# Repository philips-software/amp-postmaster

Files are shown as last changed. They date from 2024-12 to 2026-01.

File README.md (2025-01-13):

# Postmaster (Programmer Of ST Microcontrollers Attached to ST Experiment boaRds)

<!-- markdownlint-disable -->

<!-- markdownlint enable -->

## Overview

Postmaster is a device that clicks on top of an STM32 Nucleo-F767ZI board from ST Microelectronics, and through its Ethernet connector you can program the Nucleo and communicate with it.

In this way, Postmaster is usable in hardware-in-the-loop tests, where a test board is reachable through the internet. That test board can first be programmed with the correct firmware. For communicating with the test board, a client can connect to Postmaster via a websocket connection, and talk to the attached board either via a plain UART connection, or via an [ECHO](https://philips-software.github.io/amp-embedded-infra-lib/embedded_infrastructure_library/7.0.0/Echo.html) connection. This communication line is used to execute tests.

Test boards enabled by Postmaster are intended to be inherently scalable; Adding tests boards in a setup should be as simple as putting a Postmaster on top of it, configuring the Postmaster with a few labels describing the characteristics of that board, and connecting it to the internet. A locally installed proxy (also part of this archive) provides discoverability of all Postmasters in its vicinity, and routes incoming requests for boards with certain characteristics to any available board.

By providing a schematics and PCB layout, the Postmaster firmware, and various tools, this repository aims to provide a full suite of components tackling all aspects of connecting a hardware-in-the-loop test board to the cloud.

Requirements of Postmaster are documented [here](Documents/Requirements.md).

## Community

This project uses the [CODE_OF_CONDUCT](./CODE_OF_CONDUCT.md) to define expected conduct in our community. Instances of abusive, harassing, or otherwise unacceptable behavior may be reported by contacting a project [CODEOWNER](.github/CODEOWNERS)

## Changelog

See [CHANGELOG](./CHANGELOG.md) for more info on what's been changed.

## Build

The Postmaster binaries can be built by executing the following commands:

```shell
cmake --preset stm32f407
cmake --build --preset stm32f407-MinSizeRel
```

The postmaster.flex utility can be build by executing the following commands:

```shell
cmake --preset host
cmake --build --preset host-RelWithDebInfo
```

## Reporting vulnerabilities

If you find a vulnerability, please report it to us!
See [security](.github/SECURITY.md) for more information.

## Licenses

See [LICENSE](./LICENSE.md)

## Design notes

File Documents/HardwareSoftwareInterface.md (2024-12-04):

# Postmaster Hardware Software Interface

## Document Introduction
This document describes the interface between the hardware and the software of the Postmaster. It describes which peripherals and pins are connected to the hardware on the board.

## Microcontroller

The Postmaster software runs on an STM32F407VE.

## Interface

### STM32 Nucleo-F767ZI

The Postmaster is connected to the STM32 Nucleo-F767ZI in this way:

| Postmaster | STM32 Nucleo-F767ZI |
|---|---|
| PB5 | Boot0 |
| PA10, UART1 RX | PC10 UART3/4 TX |
| PB6, UART1 TX  | PC11 UART3/4 RX |
| PB7, UART1 RX  | Extern Header TX |
| PA9, UART1 TX  | Extern Header RX |
| PB4 | nReset |
| PC7, UART6 RX  | PD8 UART3 TX |

### Display

The Display is a 128x32 pixels OLED displayed controlled by an SSD1306 chip. The address of this chip is 0x3c. This chip is connected over I2C (max. frequency 400kHz) in this way:

| Postmaster | SSD1306 |
|---|---|
| PB8, I2C1 SCL | SCL |
| PB9, I2C1 SDA | SDA |

### Flash

The Flash chip is a generic JEDEC serial NOR flash chip with at capacity of at least 2MB connected over SPI in this way:

| Postmaster | Flash |
|---|---|
| PA15 | CS |
| PC10, SPI3 CLK  | CLK |
| PC11, SPI3 MISO | MISO  |
| PC12, SPI3 MOSI | MOSI  |

### Ethernet

The Postmaster is connected to a LAN8710A Ethernet PHY chip via the SMI and RMII interfaces. Its SMI address is 0.

| Postmaster | Ethernet |
|---|---|
| PA2 | mdio |
| PC1 | mdc |
| PA1 | rmiiRefClk |
| PA7 | rmiiCrsDv  |
| PC4 | rmiiRxD0 |
| PC5 | rmiiRxD1 |
| PB11 | rmiiTxEn |
| PB12 | rmiiTxD0 |
| PB13 | rmiiTxD1 |

### Debug UART

The Debug UART is connected to the TDI and DBGRQ pins of the 20-pin J-Link Connector, which is presented over USB by the J-Link adapter as a virtual COM port.

| Postmaster | Debug UART |
|---|---|
| PD8, UART3 TX | J-Link-RX (DBGRQ, pin 17) |
| PD9, UART3 RX | J-Link-TX (TDI, pin 5) |

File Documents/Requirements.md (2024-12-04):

# Postmaster Requirements Specification

## Document Introduction
This document describes the product requirements and the functional behaviour of the Postmaster.

## Purpose
The Postmaster is a tool intended to be used to download firmware to an attached STM32 Nucleo-F767ZI Board, and to connect to that board over a UART connection. The firmware to download is provided to Postmaster via its network connection.

## Requirements
- The Postmaster attaches on top of an STM32 Nucleo-F767ZI board from ST Microelectronics via the Zio connector and the BOOT0 pin on the Morpho connector.
- The Postmaster draws its power from the Nucleo board to which it is attached.
- The Postmaster uses either the SWD or one of the boot loader protocols supported by the STM32F767 to upgrade the attached Nucleo-F767ZI
- The Postmaster connects to a TCP/IP network via an Ethernet connection.
- The Postmaster displays its current network status.
- The firmware of the Postmaster is remotely upgradeable.
- The Postmaster is programmable via a J-Link programmer.
- The Postmaster is discoverable via mDNS.
  - The DNS hostname is <name>.postmaster._tcp.local.
  - Advertised attributes in the TXT record are:
    - "nm", containing the Postmaster's configured name.
    - "vs", containing the version, in format <major>.<minor>.<patch>.
    - "vf", containing the full version, in format <version>.<commit hash>.
    - "at", containing the attributes describing the setup to which the Postmaster is attached to.
- The hostname is configurable; by default it contains information unique to the microcontroller of the Postmaster.
- Firmware for either the attached Nucleo-F767ZI or the Postmaster itself can be uploaded via the HTTP protocol.
  - The path to upgrade the Postmaster is /firmware/self.
  - The path to upgrade the attached Nucleo is /firmware/target.
- Several HTTP pages which accept POST requests are available, to distinguish between upgrading the Postmaster, upgrading the Nucleo-F767ZI, or patching (writing without erasing) the Nucleo-F767ZI.
- A user-friendly HTTP page is available for dragging/dropping firmware to be uploaded and for configuration.
- On booting, the Postmaster performs a self-test.
- An HTTP page is available that shows nearby detected Postmasters.
- The UART port with which the Postmaster communications with the attached Nucleo board can be configured to be either the same UART through which the Nucleo board is upgraded, or a secondary UART port.
- The HTTP connection can be upgraded to a WebSocket connection via which the Postmaster can talk to the attached Nucleo board over a UART port without interpretation of a protocol.
  - The path for the attached Nucleo is /target/uart/programmer.
  - The path for the external header is /target/uart/external.
- The HTTP connection can be upgraded to a WebSocket connection via which the Postmaster can talk to the attached Nucleo board over a UART port via the ECHO protocol.
  - The path for the attached Nucleo is /target/echo/programmer.
  - The path for the external header is /target/echo/external.

## Assumptions
- The Postmaster is used in a secure network. The Postmaster therefore does not need access control or other security measurements.

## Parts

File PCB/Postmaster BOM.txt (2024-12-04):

Partlist exported from C:/Dev/Postmaster/PCB/Postmaster/Postmaster.sch at 17/04/2022 20:07:00

Part Value                          Device                 Package                Description                
B1   BEADSMD                        BEADSMD                0805                                              
C1   100n                           CAPACITOR0805          0805                                              
C2   100n                           CAPACITOR0805          0805                                              
C3   100n                           CAPACITOR0805          0805                                              
C4   100n                           CAPACITOR0805          0805                                              
C5   100n                           CAPACITOR0805          0805                                              
C6   100n                           CAPACITOR0805          0805                                              
C7   100n                           CAPACITOR0805          0805                                              
C8   100n                           CAPACITOR0805          0805                                              
C9   10p                            CAPACITOR0805          0805                                              
C10  10p                            CAPACITOR0805          0805                                              
C11  10p                            CAPACITOR0805          0805                                              
C12  10p                            CAPACITOR0805          0805                                              
C13  22n                            CAPACITOR0805          0805                                              
C14  470p                           CAPACITOR0805          0805                                              
C15  1u                             CAPACITOR0805          0805                                              
C16  100n                           CAPACITOR0805          0805                                              
C17  100n                           CAPACITOR0805          0805                                              
C18  100n                           CAPACITOR0805          0805                                              
C19  100n                           CAPACITOR0805          0805                                              
C20  100n                           CAPACITOR0805          0805                                              
C21  10u                            CAPACITOR0805          0805                                              
C22  10u                            CAPACITOR0805          0805                                              
C23  10u                            CAPACITOR0805          0805                                              
C24  10u                            CAPACITOR0805          0805                                              
C25  10u                            CAPACITOR0805          0805                                              
C26  2u2                            CAPACITOR0805          0805                                              
C27  2u2                            CAPACITOR0805          0805                                              
IC1  STM32F407                      STM32F407              TQFP100                                           
IC2  S25FL116K                      S25FL116KW             SOIC8-WIDE                                        
IC3  DISPLAY_32_128_SSD1306         DISPLAY_32_128_SSD1306 DISPLAY_128_32_SSD1306                            
IC4  LAN8710A                       LAN8710A               QFN32                                             
IC5  X1G0044810012 SG7050CAN 50 MHZ SM77H                  SM77H                  3.3V CMOS Clock Oscillator 
Q1   8MHz                           RESONATOR-S            RESONATOR-SMALL                                   
R1   30                             RESISTORR0805          0805                                              
R2   2k2                            RESISTORR0805          0805                                              
R3   49.9                           RESISTORR0805          0805                                              
R4   49.9                           RESISTORR0805          0805                                              
R5   49.9                           RESISTORR0805          0805                                              
R6   49.9                           RESISTORR0805          0805                                              
R7   330                            RESISTORR0805          0805                                              
R8   330                            RESISTORR0805          0805                                              
R9   10k                            RESISTORR0805          0805                                              
R10  10k                            RESISTORR0805          0805                                              
R11  12k1                           RESISTORR0805          0805                                              
R12  10k                            RESISTORR0805          0805                                              
R13  2k2                            RESISTORR0805          0805                                              
R14  1k5                            RESISTORR0805          0805                                              
R16  10k                            RESISTORR0805          0805                                              
R17  10k                            RESISTORR0805          0805                                              
R18  10k                            RESISTORR0805          0805                                              
R19  10k                            RESISTORR0805          0805                                              
R20  10k                            RESISTORR0805          0805                                              
S1   SWITCHSMD                      SWITCHSMD              SWITCH-SMD                                        
SJ1                                 SJ                     SJ                     SMD solder JUMPER          
U$1  NUCLEO-TOPLEFT                 NUCLEO-TOPLEFT         NUCLEO-TOPLEFT                                    
X1   HEADER-IDC-10-2                HEADER-IDC-10-2        IDC-10_2                                          
X2   J00-0065NL                     J00-0065NL             ETHERNET

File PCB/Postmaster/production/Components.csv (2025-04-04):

Comment | Designator | Footprint | JLCPCBPart
22nF | C1 | Capacitor_SMD:C_0603_1608Metric | C21122
10p | C2,C3,C4,C5 | Capacitor_SMD:C_0603_1608Metric | C1634
10u | C6,C8,C12,C19,C22 | Capacitor_SMD:C_0603_1608Metric | C19702
100n | C7,C10,C13,C14,C15,C18,C20,C21,C23,C24,C25,C26,C27 | Capacitor_SMD:C_0603_1608Metric | C14663
470p | C9 | Capacitor_SMD:C_0603_1608Metric | C1620
1u | C11 | Capacitor_SMD:C_0805_2012Metric | C15849
2u2 | C16,C17 | Capacitor_SMD:C_0603_1608Metric | C23630
FerriteBead | FB1 | Inductor_SMD:L_0603_1608Metric | C1002
Conn_01x02 | J1 | Connector_PinSocket_2.54mm:PinSocket_1x02_P2.54mm_Vertical | C7509512
Conn_02x08_Odd_Even | J2 | Connector_PinHeader_2.54mm:PinHeader_2x08_P2.54mm_Vertical | C5383108
Conn_01x04 | J3,J4 | Connector_PinHeader_2.54mm:PinHeader_1x04_P2.54mm_Vertical | C7430360
Conn_01x03 | J5 | Connector_PinHeader_2.54mm:PinHeader_1x03_P2.54mm_Vertical
Conn_02x10_Odd_Even | J6 | Connector_IDC:IDC-Header_2x10_P2.54mm_Vertical | C3405
J00-0065NL | P1 | PostmasterParts:PULSE_J00-0065NL | C3178480
330 | R1,R2 | Resistor_SMD:R_0603_1608Metric | C23138
49.9 | R3,R4,R5,R6 | Resistor_SMD:R_0603_1608Metric | C269902
12k1 | R7 | Resistor_SMD:R_0603_1608Metric | C22864
10k | R8,R9,R10,R11,R12,R13,R14,R15 | Resistor_SMD:R_0603_1608Metric | C25804
1k5 | R16 | Resistor_SMD:R_0603_1608Metric | C22843
2k2 | R17,R18 | Resistor_SMD:R_0603_1608Metric | C4190
SW_Push | SW2 | Button_Switch_SMD:SW_SPST_TL3305B
LAN8710A | U1 | Package_DFN_QFN:QFN-32-1EP_5x5mm_P0.5mm_EP3.3x3.3mm_ThermalVias | C46185
STM32F407VETx | U2 | Package_QFP:LQFP-100_14x14mm_P0.5mm | C28730
S25FL064LABMFI013 | U3 | Package_SO:SOIC-8_5.23x5.23mm_P1.27mm | C2951282
TFOM50M4RHKCNT2T | Y1 | Oscillator:Oscillator_SMD_Abracon_ASE-4Pin_3.2x2.5mm | C454615
CSTNE8M00G550000R0 | Y2 | Crystal:Resonator_SMD_Murata_CSTxExxV-3Pin_3.0x1.1mm | C341522

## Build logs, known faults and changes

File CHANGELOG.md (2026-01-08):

# CHANGELOG

All notable changes to this project will be documented in this file.

The format is based on [Keep a Changelog](https://keepachangelog.com/) and this project adheres to [Semantic Versioning](https://semver.org/).

## unreleased

- Enabled warnings as error, requires CMake 3.24

## [0.5.0](https://github.com/philips-software/amp-postmaster/compare/v0.4.2...v0.5.0) (2026-01-08)

### Features

* **deps:** Bump the git-submodules group with 3 updates ([#157](https://github.com/philips-software/amp-postmaster/issues/157)) ([c72f827](https://github.com/philips-software/amp-postmaster/commit/c72f82746b9ce9e1db89811cab0ec1cbe0d8ef59))

### Bug Fixes

* Fill out content type and content length ([#165](https://github.com/philips-software/amp-postmaster/issues/165)) ([e9c7b0c](https://github.com/philips-software/amp-postmaster/commit/e9c7b0c233c8393ec904399f9182b687d82dedd9))
* Firmware upgrade ([#167](https://github.com/philips-software/amp-postmaster/issues/167)) ([95f315a](https://github.com/philips-software/amp-postmaster/commit/95f315a3d97898ae5ea2628a7af4c72bc2e6cbd3))
* Update display when hostname changes ([#168](https://github.com/philips-software/amp-postmaster/issues/168)) ([a214a2b](https://github.com/philips-software/amp-postmaster/commit/a214a2b18682dc2801df2f195e07964dcda485f7))

## [0.4.2](https://github.com/philips-software/amp-postmaster/compare/v0.4.1...v0.4.2) (2026-01-07)

### Bug Fixes

* Release version in upg file names ([#160](https://github.com/philips-software/amp-postmaster/issues/160)) ([20e5a0c](https://github.com/philips-software/amp-postmaster/commit/20e5a0c7634da09676dcf33ed5a433dc6a814ab6))

### Continuous Integration

* Substitute main version in upgrade pack ([e0ad9e0](https://github.com/philips-software/amp-postmaster/commit/e0ad9e03df9483b4bf938144bd519e11c37fa9e9))

## [0.4.1](https://github.com/philips-software/amp-postmaster/compare/v0.4.0...v0.4.1) (2026-01-05)

### Bug Fixes

* Create upgrade pack in release builds ([#155](https://github.com/philips-software/amp-postmaster/issues/155)) ([a97534e](https://github.com/philips-software/amp-postmaster/commit/a97534e0ec7223d1838d8aff6ec41813f2d24187))

## [0.4.0](https://github.com/philips-software/amp-postmaster/compare/v0.3.1...v0.4.0) (2026-01-05)

### Features

* **deps:** Bump the git-submodules group across 1 directory with 3 updates ([#153](https://github.com/philips-software/amp-postmaster/issues/153)) ([c136812](https://github.com/philips-software/amp-postmaster/commit/c1368121505cd80a841d12cf738da41e73dda4e1))

### Bug Fixes

* Install postmaster binaries ([#146](https://github.com/philips-software/amp-postmaster/issues/146)) ([8429844](https://github.com/philips-software/amp-postmaster/commit/842984459ac9b12047a313f3510fe26addfba380))

## [0.3.1](https://github.com/philips-software/amp-postmaster/compare/v0.3.0...v0.3.1) (2025-12-19)

### Bug Fixes

* Remove provenance and devcontainer templates ([#144](https://github.com/philips-software/amp-postmaster/issues/144)) ([d9b699c](https://github.com/philips-software/amp-postmaster/commit/d9b699c77f3d389f975c6d5e6fca4d7e41745df3))

## [0.3.0](https://github.com/philips-software/amp-postmaster/compare/v0.2.0...v0.3.0) (2025-12-19)

### Features

* **deps:** Bump the git-submodules group across 1 directory with 3 updates ([#141](https://github.com/philips-software/amp-postmaster/issues/141)) ([a58cd70](https://github.com/philips-software/amp-postmaster/commit/a58cd70d755250cc557a9f6fa9cc9cd275da8494))

## [0.2.0](https://github.com/philips-software/amp-postmaster/compare/v0.1.0...v0.2.0) (2025-12-17)

### Features

* Add kicad design for Postmaster ([#51](https://github.com/philips-software/amp-postmaster/issues/51)) ([5b0d990](https://github.com/philips-software/amp-postmaster/commit/5b0d9900bc231ba2a10e43529f035f32f8af2cdc))
* **deps:** Bump the git-submodules group across 1 directory with 3 updates ([#65](https://github.com/philips-software/amp-postmaster/issues/65)) ([9473c1d](https://github.com/philips-software/amp-postmaster/commit/9473c1d3efd021cd0ad530f573b0ce2613c047ab))
* Publish flex docker image ([#5](https://github.com/philips-software/amp-postmaster/issues/5)) ([e3fc05b](https://github.com/philips-software/amp-postmaster/commit/e3fc05ba389df427653b57ea76c12f334beb6b95))

### Bug Fixes

* Add tests for FlashAligner and fix it ([#88](https://github.com/philips-software/amp-postmaster/issues/88)) ([2133475](https://github.com/philips-software/amp-postmaster/commit/2133475931bbcfbf4f7fa093ad749119efa9695c))
* Align flash writes to 16 bytes ([#80](https://github.com/philips-software/amp-postmaster/issues/80)) ([0e34eeb](https://github.com/philips-software/amp-postmaster/commit/0e34eeb55f1ba87ccf2061490d2d1f1caafac746))
* Attach from correct SharedPtr ([f00cf1e](https://github.com/philips-software/amp-postmaster/commit/f00cf1e85892faf4e9c6b0aa95d7596bd946d101))
* Fix various problems ([42f0029](https://github.com/philips-software/amp-postmaster/commit/42f00295daf3bd058f0f94b6982cb21b694c2bf2))
* Incorrect tag in dockerfile causes devcontainer build failure ([#118](https://github.com/philips-software/amp-postmaster/issues/118)) ([31f71a4](https://github.com/philips-software/amp-postmaster/commit/31f71a4e9d64e9834987886dd61a1d6c54a75a64))
* Various Echo fixes ([220c4be](https://github.com/philips-software/amp-postmaster/commit/220c4be60fb67f997dff082bfabd027347f24174))

## v0.0.1

- Example Release

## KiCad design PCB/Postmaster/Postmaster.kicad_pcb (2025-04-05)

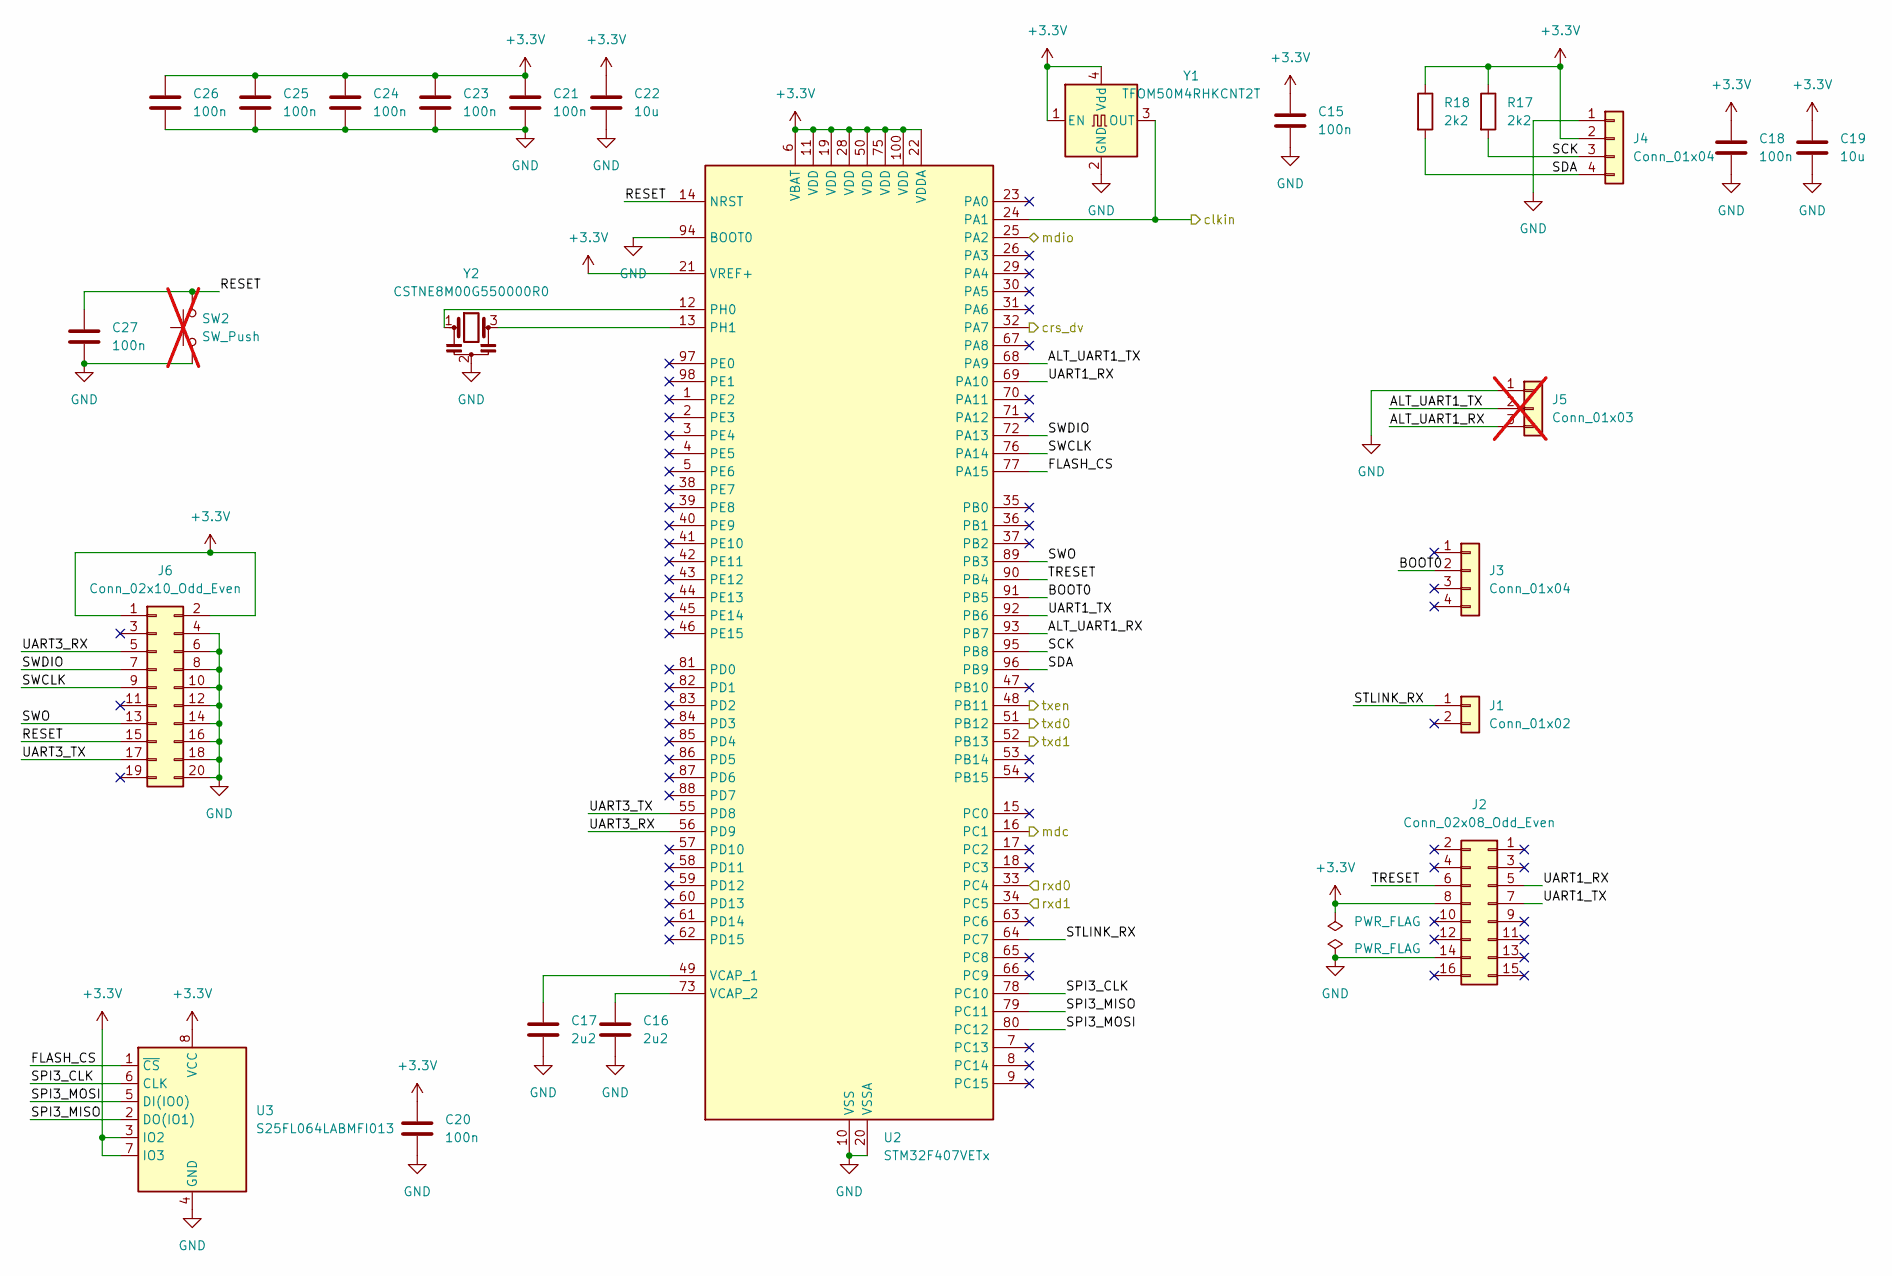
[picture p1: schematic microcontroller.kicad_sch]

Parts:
C15, C18, C20, C21, C23, C24, C25, C26, C27: 100n; C_0603_1608Metric; JLCPCBPart C14663
C16, C17: 2u2; C_0603_1608Metric; JLCPCBPart C23630
C19, C22: 10u; C_0603_1608Metric; JLCPCBPart C19702
J1: Conn_01x02; PinSocket_1x02_P2.54mm_Vertical; JLCPCBPart C7509512
J2: Conn_02x08_Odd_Even; PinHeader_2x08_P2.54mm_Vertical; JLCPCBPart C5383108
J3, J4: Conn_01x04; PinHeader_1x04_P2.54mm_Vertical; JLCPCBPart C7430360
J5: Conn_01x03; PinHeader_1x03_P2.54mm_Vertical; not fitted
J6: Conn_02x10_Odd_Even; IDC-Header_2x10_P2.54mm_Vertical; JLCPCBPart C3405
R17, R18: 2k2; R_0603_1608Metric; JLCPCBPart C4190
SW2: SW_Push; SW_SPST_TL3305B; not fitted
U2: STM32F407VETx; LQFP-100_14x14mm_P0.5mm; JLCPCBPart C28730
U3: S25FL064LABMFI013; SOIC-8_5.23x5.23mm_P1.27mm; JLCPCBPart C2951282
Y1: TFOM50M4RHKCNT2T; Oscillator_SMD_Abracon_ASE-4Pin_3.2x2.5mm; JLCPCBPart C454615
Y2: CSTNE8M00G550000R0; Resonator_SMD_Murata_CSTxExxV-3Pin_3.0x1.1mm; JLCPCBPart C341522

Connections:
+3.3V: C15.1, C18.1, C19.1, C20.1, C21.1, C22.1, C23.1, C24.1, C25.1, C26.1, J2.8, J4.2, J6.1, J6.2, R17.1, R18.1, U2.6 (VBAT), U2.11 (VDD), U2.19 (VDD), U2.21 (VREF+), U2.22 (VDDA), U2.28 (VDD), U2.50 (VDD), U2.75 (VDD), U2.100 (VDD), U3.3 (IO2), U3.7 (IO3), U3.8 (VCC), Y1.1 (EN), Y1.4 (Vdd); also elsewhere on the board
/Ethernet/clkin: U2.24 (PA1), Y1.3 (OUT); also elsewhere on the board
/Ethernet/crs_dv: U2.32 (PA7); also elsewhere on the board
/Ethernet/mdc: U2.16 (PC1); also elsewhere on the board
/Ethernet/mdio: U2.25 (PA2); also elsewhere on the board
/Ethernet/rxd0: U2.33 (PC4); also elsewhere on the board
/Ethernet/rxd1: U2.34 (PC5); also elsewhere on the board
/Ethernet/txd0: U2.51 (PB12); also elsewhere on the board
/Ethernet/txd1: U2.52 (PB13); also elsewhere on the board
/Ethernet/txen: U2.48 (PB11); also elsewhere on the board
/Microcontroller/ALT_UART1_RX: J5.3, U2.93 (PB7)
/Microcontroller/ALT_UART1_TX: J5.2, U2.68 (PA9)
/Microcontroller/BOOT0: J3.2, U2.91 (PB5)
/Microcontroller/FLASH_CS: U2.77 (PA15), U3.1 (~CS)
/Microcontroller/RESET: C27.1, J6.15, SW2.2, U2.14 (NRST)
/Microcontroller/SCK: J4.3, R17.2, U2.95 (PB8)
/Microcontroller/SDA: J4.4, R18.2, U2.96 (PB9)
/Microcontroller/SPI3_CLK: U2.78 (PC10), U3.6 (CLK)
/Microcontroller/SPI3_MISO: U2.79 (PC11), U3.2 (DO(IO1))
/Microcontroller/SPI3_MOSI: U2.80 (PC12), U3.5 (DI(IO0))
/Microcontroller/STLINK_RX: J1.1, U2.64 (PC7)
/Microcontroller/SWCLK: J6.9, U2.76 (PA14)
/Microcontroller/SWDIO: J6.7, U2.72 (PA13)
/Microcontroller/SWO: J6.13, U2.89 (PB3)
/Microcontroller/TRESET: J2.6, U2.90 (PB4)
/Microcontroller/UART1_RX: J2.5, U2.69 (PA10)
/Microcontroller/UART1_TX: J2.7, U2.92 (PB6)
/Microcontroller/UART3_RX: J6.5, U2.56 (PD9)
/Microcontroller/UART3_TX: J6.17, U2.55 (PD8)
GND: C15.2, C16.2, C17.2, C18.2, C19.2, C20.2, C21.2, C22.2, C23.2, C24.2, C25.2, C26.2, C27.2, J2.14, J4.1, J5.1, J6.4, J6.6, J6.8, J6.10, J6.12, J6.14, J6.16, J6.18, J6.20, SW2.1, U2.10 (VSS), U2.20 (VSSA), U2.27 (VSS), U2.74 (VSS), U2.94 (BOOT0), U2.99 (VSS), U3.4 (GND), Y1.2 (GND), Y2.2; also elsewhere on the board
unnamed: U2.12 (PH0), Y2.1
unnamed: U2.13 (PH1), Y2.3
unnamed: C17.1, U2.49 (VCAP_1)
unnamed: C16.1, U2.73 (VCAP_2)

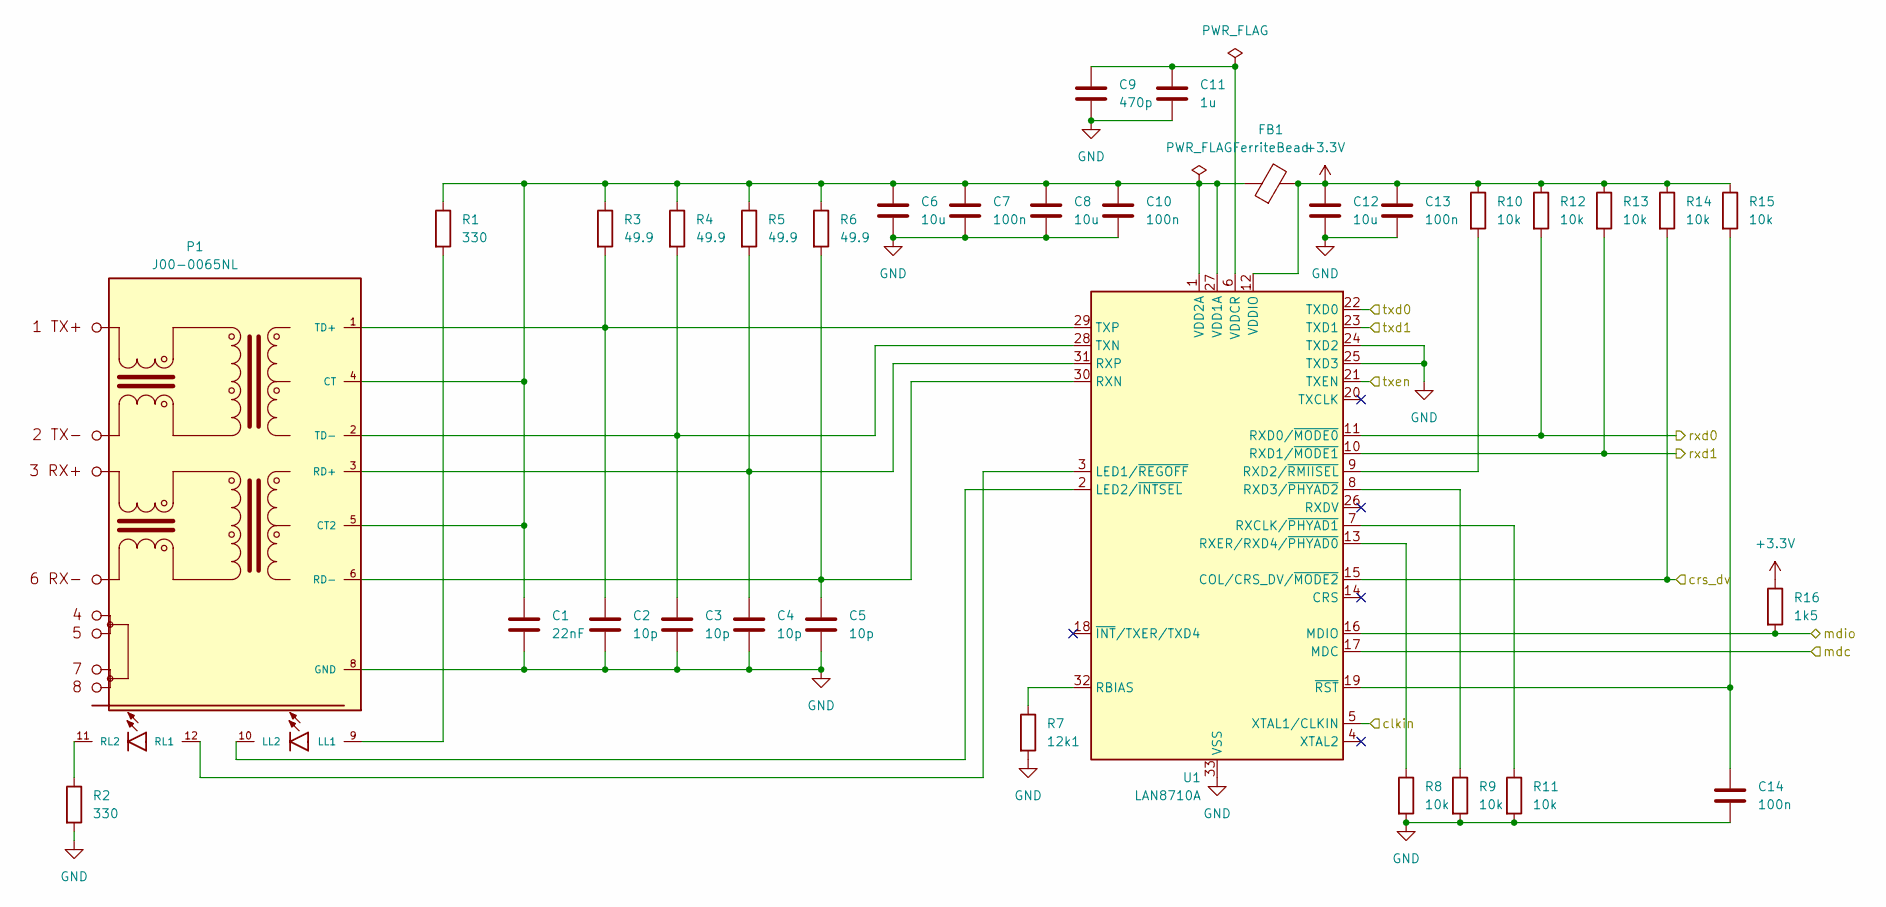
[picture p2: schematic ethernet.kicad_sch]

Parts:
C1: 22nF; C_0603_1608Metric; JLCPCBPart C21122
C2, C3, C4, C5: 10p; C_0603_1608Metric; JLCPCBPart C1634
C6, C8, C12: 10u; C_0603_1608Metric; JLCPCBPart C19702
C7, C10, C13, C14: 100n; C_0603_1608Metric; JLCPCBPart C14663
C9: 470p; C_0603_1608Metric; JLCPCBPart C1620
C11: 1u; C_0805_2012Metric; JLCPCBPart C15849
FB1: FerriteBead; L_0603_1608Metric; JLCPCBPart C1002
P1: J00-0065NL; PULSE_J00-0065NL; JLCPCBPart C3178480
R1, R2: 330; R_0603_1608Metric; JLCPCBPart C23138
R3, R4, R5, R6: 49.9; R_0603_1608Metric; JLCPCBPart C269902
R7: 12k1; R_0603_1608Metric; JLCPCBPart C22864
R8, R9, R10, R11, R12, R13, R14, R15: 10k; R_0603_1608Metric; JLCPCBPart C25804
R16: 1k5; R_0603_1608Metric; JLCPCBPart C22843
U1: LAN8710A; QFN-32-1EP_5x5mm_P0.5mm_EP3.3x3.3mm_ThermalVias; JLCPCBPart C46185

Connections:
+3.3V: C12.1, C13.1, FB1.2, R10.1, R12.1, R13.1, R14.1, R15.1, R16.1, U1.12 (VDDIO); also elsewhere on the board
/Ethernet/clkin: U1.5 (XTAL1/CLKIN); also elsewhere on the board
/Ethernet/crs_dv: R14.2, U1.15 (COL/CRS_DV/~MODE2); also elsewhere on the board
/Ethernet/mdc: U1.17 (MDC); also elsewhere on the board
/Ethernet/mdio: R16.2, U1.16 (MDIO); also elsewhere on the board
/Ethernet/rxd0: R12.2, U1.11 (RXD0/~MODE0); also elsewhere on the board
/Ethernet/rxd1: R13.2, U1.10 (RXD1/~MODE1); also elsewhere on the board
/Ethernet/txd0: U1.22 (TXD0); also elsewhere on the board
/Ethernet/txd1: U1.23 (TXD1); also elsewhere on the board
/Ethernet/txen: U1.21 (TXEN); also elsewhere on the board
GND: C1.2, C2.2, C3.2, C4.2, C5.2, C6.2, C7.2, C8.2, C9.2, C10.2, C11.2, C12.2, C13.2, C14.2, P1.8 (GND), R2.2, R7.2, R8.2, R9.2, R11.2, U1.24 (TXD2), U1.25 (TXD3), U1.33 (VSS); also elsewhere on the board
unnamed: C1.1, C6.1, C7.1, C8.1, C10.1, FB1.1, P1.4 (CT), P1.5 (CT2), R1.1, R3.1, R4.1, R5.1, R6.1, U1.1 (VDD2A), U1.27 (VDD1A)
unnamed: P1.9 (LL1), R1.2
unnamed: P1.10 (LL2), U1.2 (LED2/~INTSEL)
unnamed: C4.1, P1.3 (RD+), R5.2, U1.31 (RXP)
unnamed: C5.1, P1.6 (RD-), R6.2, U1.30 (RXN)
unnamed: P1.12 (RL1), U1.3 (LED1/~REGOFF)
unnamed: P1.11 (RL2), R2.1
unnamed: C2.1, P1.1 (TD+), R3.2, U1.29 (TXP)
unnamed: C3.1, P1.2 (TD-), R4.2, U1.28 (TXN)
unnamed: R7.1, U1.32 (RBIAS)
unnamed: R11.1, U1.7 (RXCLK/~PHYAD1)
unnamed: R10.2, U1.9 (RXD2/~RMIISEL)
unnamed: R9.1, U1.8 (RXD3/~PHYAD2)
unnamed: R8.1, U1.13 (RXER/RXD4/~PHYAD0)
unnamed: C9.1, C11.1, U1.6 (VDDCR)
unnamed: C14.1, R15.2, U1.19 (~RST)

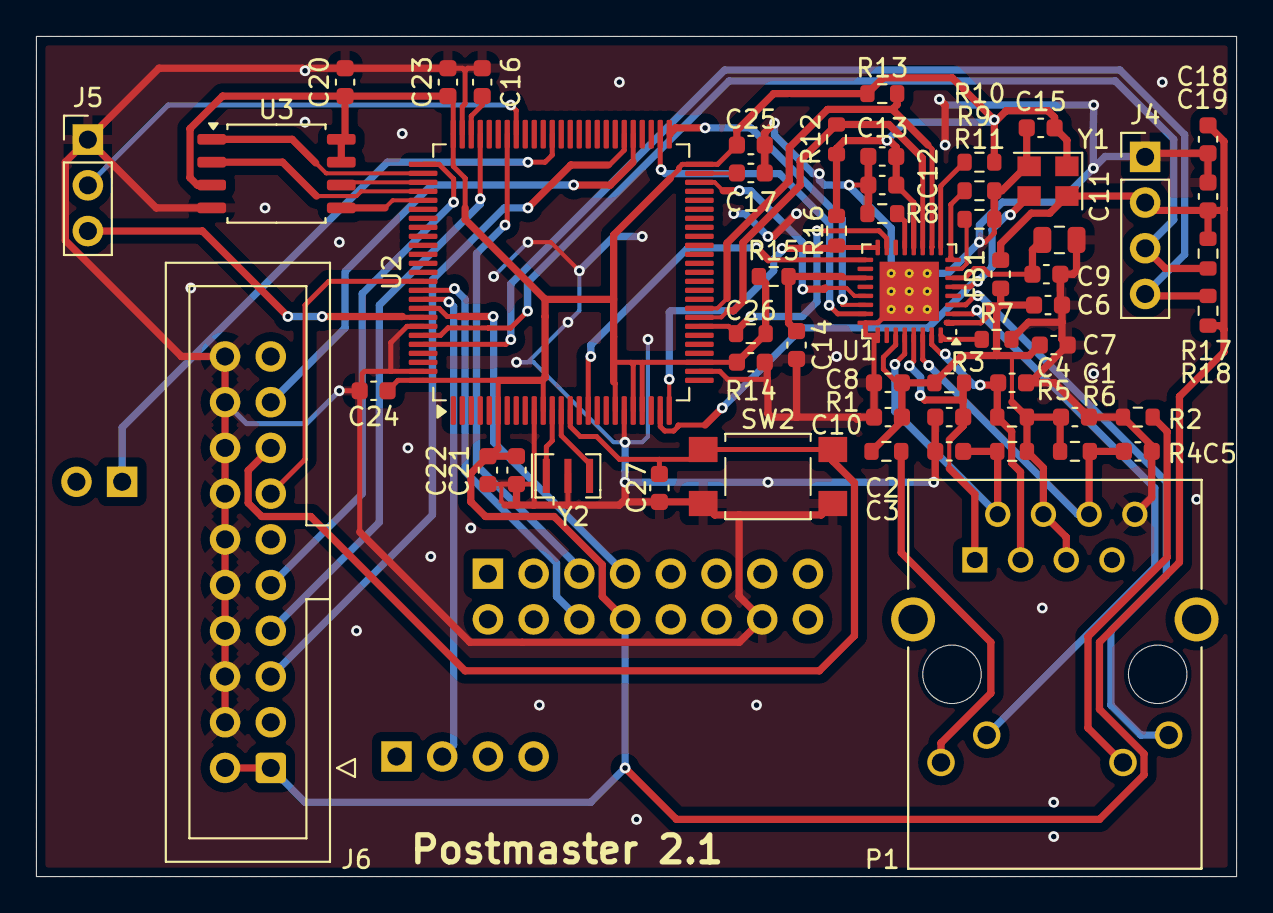
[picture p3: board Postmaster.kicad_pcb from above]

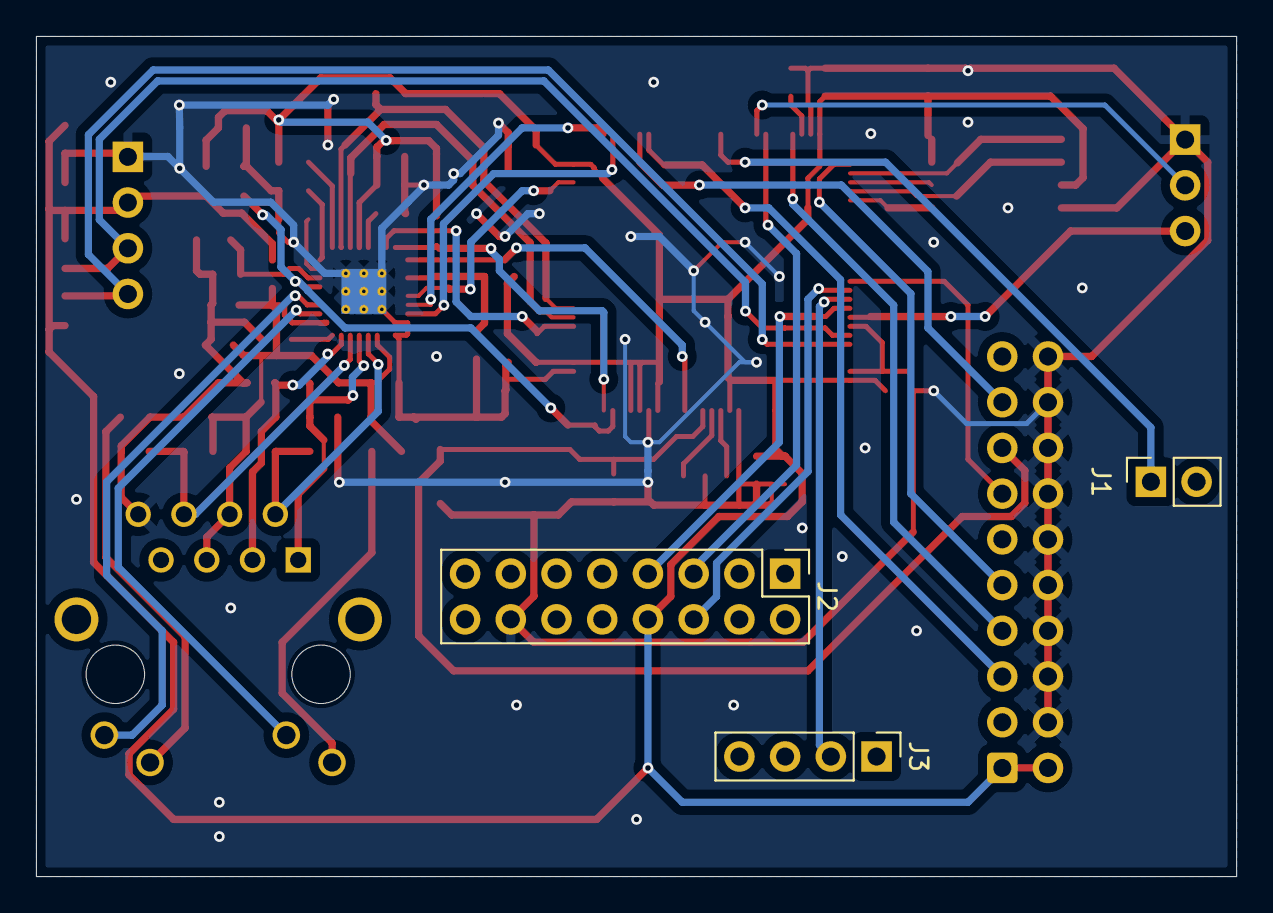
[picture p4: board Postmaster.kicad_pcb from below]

Board: 2 copper layers, 66.7 x 46.7 mm, 59 parts (3 on the bottom side), 50 nets.

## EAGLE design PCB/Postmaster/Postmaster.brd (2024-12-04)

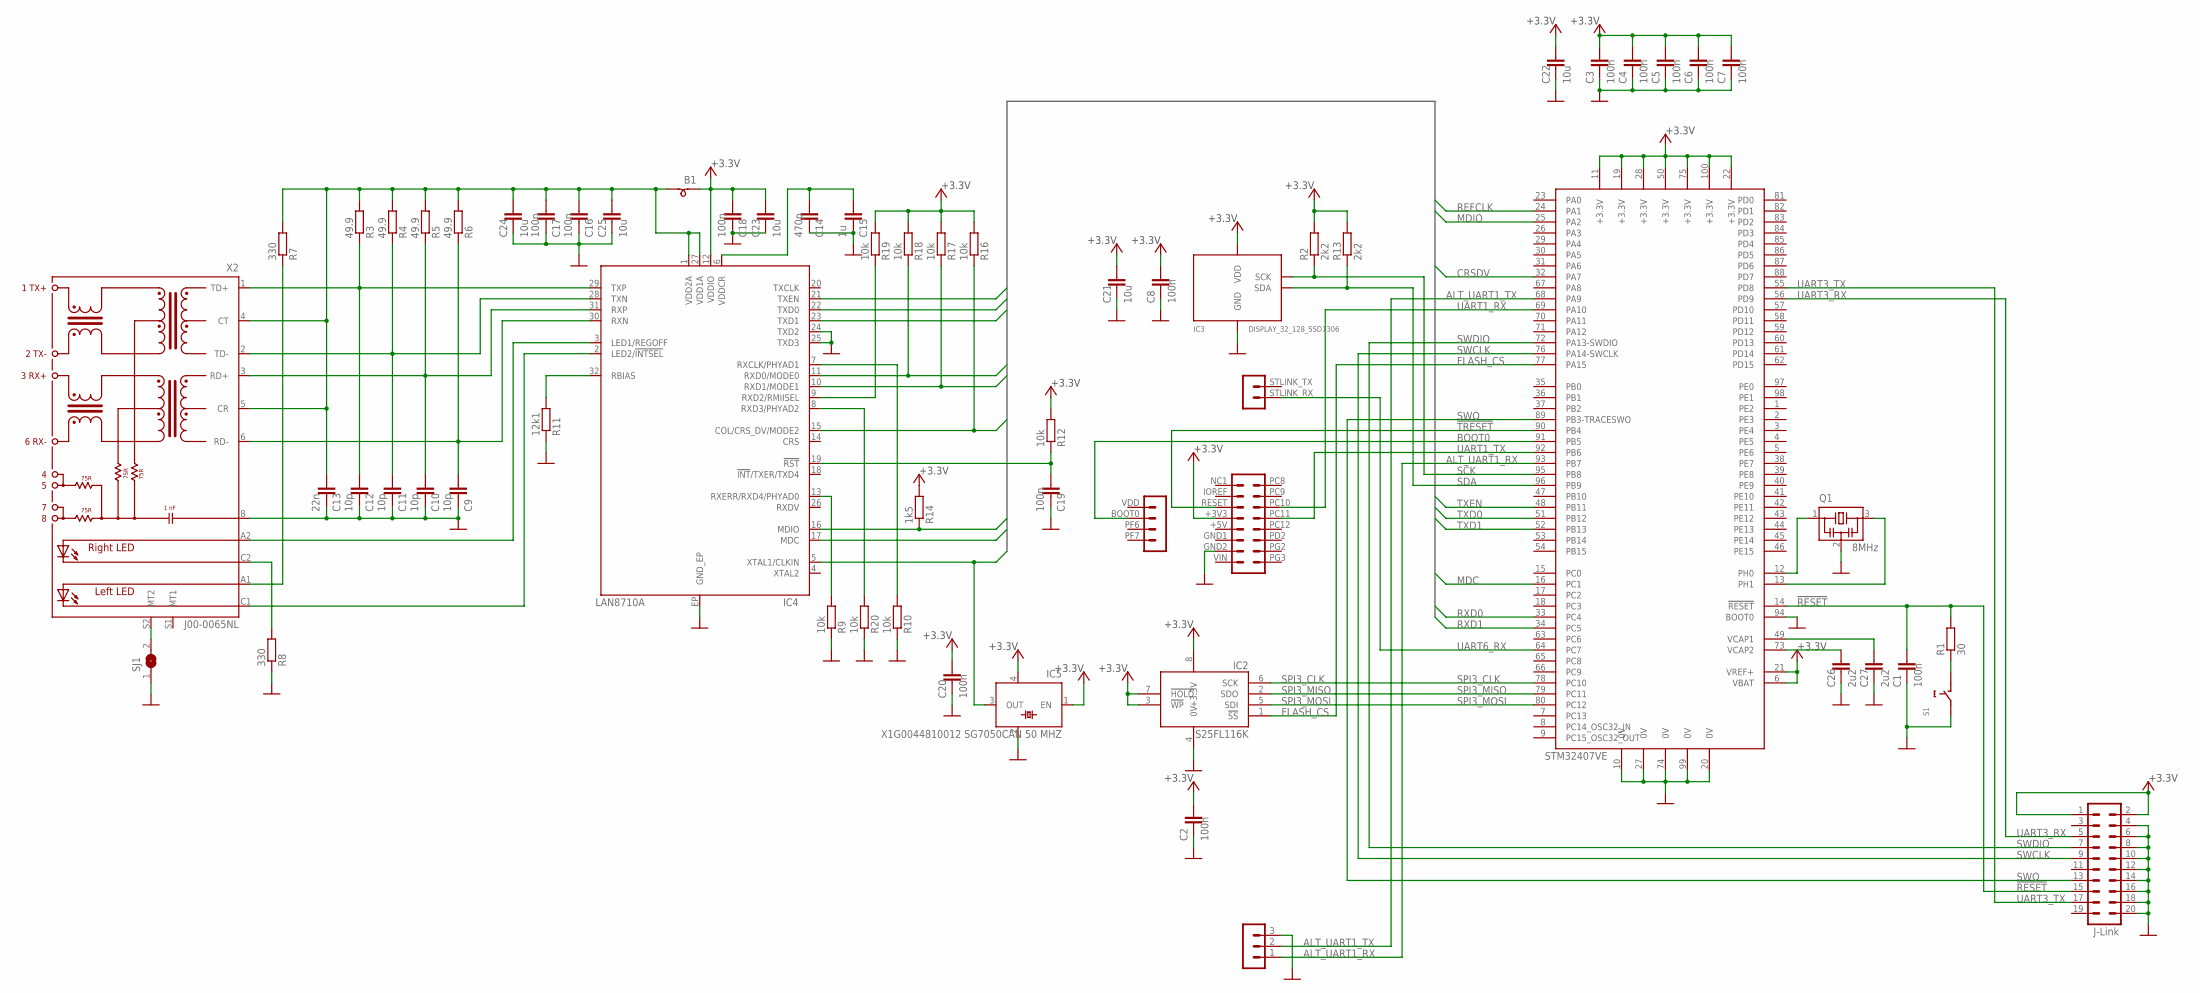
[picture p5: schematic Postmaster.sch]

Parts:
B1: BEADSMD; 0805
C1, C2, C3, C4, C5, C6, C7, C8, C16, C17, C18, C19, C20: 100n; 0805
C9, C10, C11, C12: 10p; 0805
C13: 22n; 0805
C14: 470p; 0805
C15: 1u; 0805
C21, C22, C23, C24, C25: 10u; 0805
C26, C27: 2u2; 0805
IC1: STM32F407; TQFP100
IC2: S25FL116K; SOIC8-WIDE
IC3: DISPLAY_32_128_SSD1306; DISPLAY_128_32_SSD1306
IC4: LAN8710A; QFN32
IC5: X1G0044810012 SG7050CAN 50 MHZ; SM77H
Q1: 8MHz; RESONATOR-SMALL
R1: 30; 0805
R2, R13: 2k2; 0805
R3, R4, R5, R6: 49.9; 0805
R7, R8: 330; 0805
R9, R10, R12, R16, R17, R18, R19, R20: 10k; 0805
R11: 12k1; 0805
R14: 1k5; 0805
S1: SWITCHSMD; SWITCH-SMD
SJ1: SJ
U$1: NUCLEO-TOPLEFT
U$3: HEADER-MALE-3
X1: HEADER-IDC-10-2; IDC-10_2
X2: J00-0065NL; ETHERNET

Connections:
0V: C1.2, C2.2, C3.2, C4.2, C5.2, C6.2, C7.2, C8.2, C9.2, C10.2, C11.2, C12.2, C13.2, C14.2, C15.2, C16.2, C17.2, C18.2, C19.2, C20.2, C21.2, C22.2, C23.2, C24.2, C25.2, C26.2, C27.2, IC1.10 (0V), IC1.20 (0V), IC1.27 (0V), IC1.74 (0V), IC1.94 (BOOT0), IC1.99 (0V), IC2.4 (0V), IC3.GND, IC4.24 (TXD2), IC4.25 (TXD3), IC4.EP (GND_EP), IC5.2 (0V), Q1.2, R8.1, R9.1, R10.1, R11.1, R20.1, S1.3 (2), S1.4 (2), SJ1.1, U$1.GND2 (13), U$3.3, X1.4, X1.6, X1.8, X1.10, X1.12, X1.14, X1.16, X1.18, X1.20, X2.8
!RESET!: C1.1, IC1.14 (!RESET!), R1.2, X1.15
!TRESET!: IC1.90 (PB4), U$1.RESET (5)
+3.3V: B1.1, C2.1, C3.1, C4.1, C5.1, C6.1, C7.1, C8.1, C18.1, C20.1, C21.1, C22.1, C23.1, IC1.6 (VBAT), IC1.11 (+3.3V), IC1.19 (+3.3V), IC1.21 (VREF+), IC1.22 (+3.3V), IC1.28 (+3.3V), IC1.50 (+3.3V), IC1.75 (+3.3V), IC1.100 (+3.3V), IC2.3 (!WP!), IC2.7 (!HOLD!), IC2.8 (+3.3V), IC3.VCC (VDD), IC4.12 (VDDIO), IC5.1 (EN), IC5.4 (+3.3V), R2.2, R12.2, R13.2, R14.2, R16.2, R17.2, R18.2, R19.2, U$1.+3V3 (7), X1.1, X1.2
ALT_UART1_RX: IC1.93 (PB7), U$3.1
ALT_UART1_TX: IC1.68 (PA9), U$3.2
BOOT0: IC1.91 (PB5), U$1.BOOT0 (2)
CRSDV: IC1.32 (PA7), IC4.15 (COL/CRS_DV/MODE2), R16.1
FLASH_CS: IC1.77 (PA15), IC2.1 (!SS!)
MDC: IC1.16 (PC1), IC4.17 (MDC)
MDIO: IC1.25 (PA2), IC4.16 (MDIO), R14.1
unnamed: C26.1, IC1.73 (VCAP2)
unnamed: R1.1, S1.1, S1.2 (1)
unnamed: C27.1, IC1.49 (VCAP1)
unnamed: R7.1, X2.A1 (A-L)
unnamed: IC4.3 (LED1/REGOFF), X2.A2 (A-R)
unnamed: R8.2, X2.C2 (C-R)
unnamed: IC1.12 (PH0), Q1.1
unnamed: IC1.13 (PH1), Q1.3
unnamed: C12.1, IC4.29 (TXP), R3.1, X2.1 (TD+)
unnamed: C11.1, IC4.28 (TXN), R4.1, X2.2 (TD-)
unnamed: C10.1, IC4.31 (RXP), R5.1, X2.3 (RD+)
unnamed: C9.1, IC4.30 (RXN), R6.1, X2.6 (RD-)
unnamed: IC4.2 (LED2/!INTSEL!), X2.C1 (C-L)
unnamed: IC4.13 (RXERR/RXD4/PHYAD0), R9.2
unnamed: IC4.7 (RXCLK/PHYAD1), R10.2
unnamed: IC4.32 (RBIAS), R11.2
unnamed: C14.1, C15.1, IC4.6 (VDDCR)
unnamed: SJ1.2, X2.S2 (MT2)
unnamed: B1.2, C13.1, C16.1, C17.1, C24.1, C25.1, IC4.1 (VDD2A), IC4.27 (VDD1A), R3.2, R4.2, R5.2, R6.2, R7.2, X2.4 (CT), X2.5 (CR)
unnamed: C19.1, IC4.19 (!RST!), R12.1
unnamed: IC4.8 (RXD3/PHYAD2), R20.2
unnamed: IC4.9 (RXD2/RMIISEL), R19.1
REFCLK: IC1.24 (PA1), IC4.5 (XTAL1/CLKIN), IC5.3 (OUT)
RXD0: IC1.33 (PC4), IC4.11 (RXD0/MODE0), R18.1
RXD1: IC1.34 (PC5), IC4.10 (RXD1/MODE1), R17.1
SCK: IC1.95 (PB8), IC3.SCK, R2.1
SDA: IC1.96 (PB9), IC3.SDA, R13.1
SPI3_CLK: IC1.78 (PC10), IC2.6 (SCK)
SPI3_MISO: IC1.79 (PC11), IC2.2 (SDO)
SPI3_MOSI: IC1.80 (PC12), IC2.5 (SDI)
SWCLK: IC1.76 (PA14-SWCLK), X1.9
SWDIO: IC1.72 (PA13-SWDIO), X1.7
SWO: IC1.89 (PB3-TRACESWO), X1.13
TXD0: IC1.51 (PB12), IC4.22 (TXD0)
TXD1: IC1.52 (PB13), IC4.23 (TXD1)
TXEN: IC1.48 (PB11), IC4.21 (TXEN)
UART1_RX: IC1.69 (PA10), U$1.PC10 (6)
UART1_TX: IC1.92 (PB6), U$1.PC11 (8)
UART3_RX: IC1.56 (PD9), X1.5
UART3_TX: IC1.55 (PD8), X1.17
UART6_RX: IC1.64 (PC7), U$1.STLINK_RX (1)

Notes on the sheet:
J-Link
STM32407VE

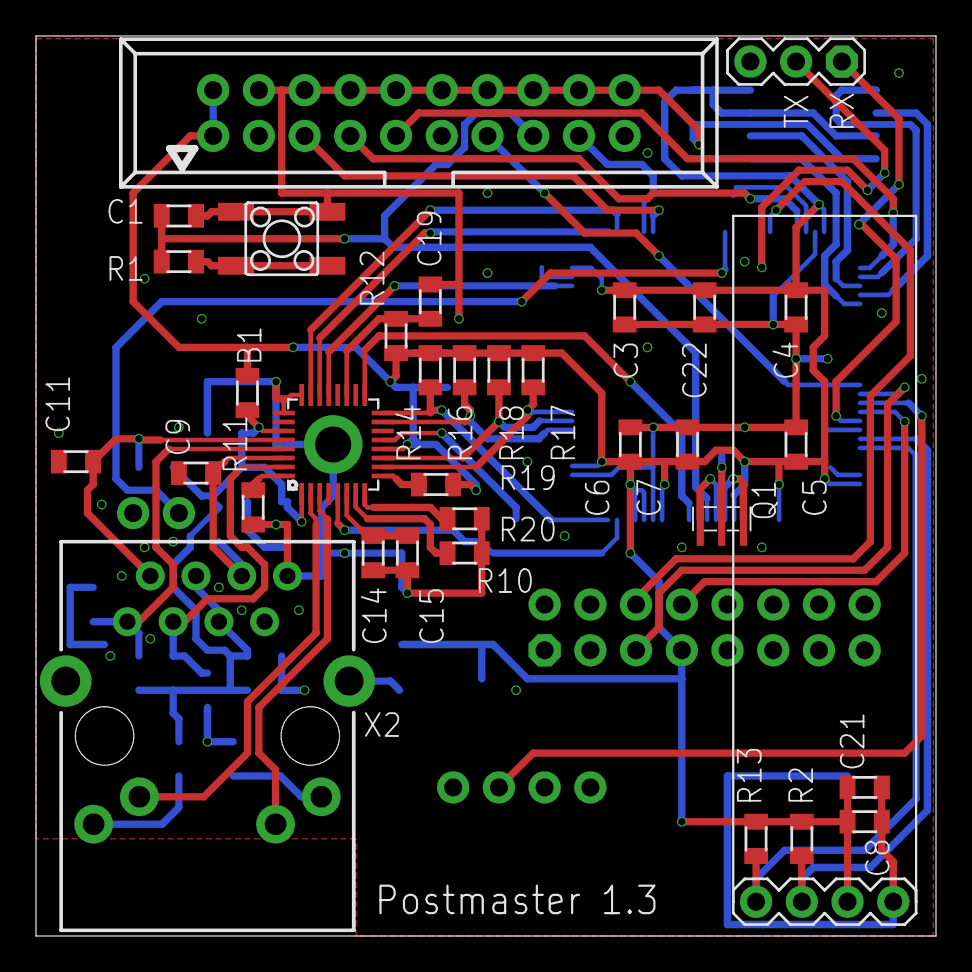
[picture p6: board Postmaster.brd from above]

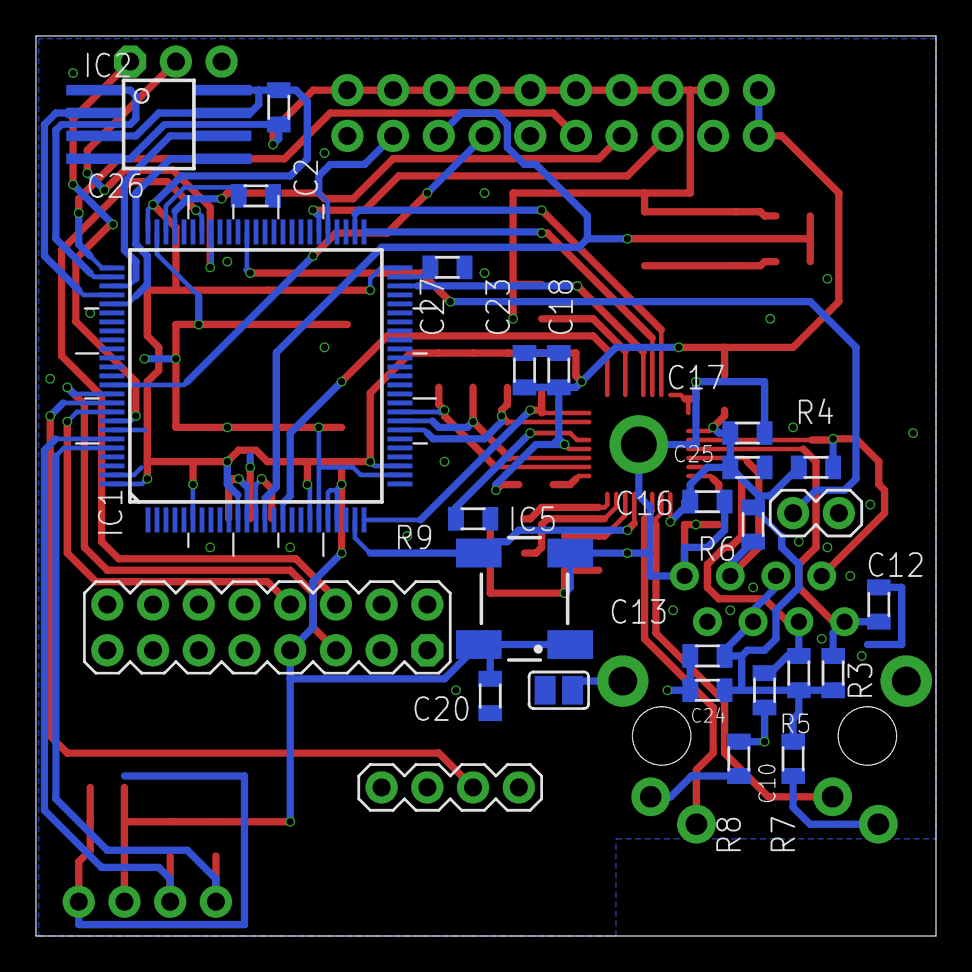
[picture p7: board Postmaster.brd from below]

Board: 2 copper layers, 50.0 x 50.0 mm, 59 parts (25 on the bottom side), 52 nets.

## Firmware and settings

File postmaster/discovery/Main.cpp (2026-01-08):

// Start Traefik with: docker run -it --rm -p 80:80 -p 8080:8080 traefik:v2.10 --api.insecure=true --providers.http.endpoint=http://host.docker.internal:9000/api --log.level=DEBUG

#include "hal/generic/TimerServiceGeneric.hpp"
#include "infra/stream/StdStringOutputStream.hpp"
#include "infra/syntax/JsonFormatter.hpp"
#include "postmaster/application/MdnsDiscovery.hpp"
#include "services/network/Http.hpp"
#include "services/network/HttpErrors.hpp"
#include "services/network/HttpServer.hpp"
#include "services/network_instantiations/NetworkAdapter.hpp"
#include "services/tracer/GlobalTracer.hpp"

class HttpPageReverseProxyConfiguration
    : public services::SimpleHttpPage
    , protected services::HttpResponse
{
public:
    HttpPageReverseProxyConfiguration(infra::BoundedConstString path, application::PostmasterDiscovery& discovery);

    // Implementation of SimpleHttpPage
    bool ServesRequest(const infra::Tokenizer& pathTokens) const override;
    void RespondToRequest(services::HttpRequestParser& parser, services::HttpServerConnection& connection) override;

protected:
    // Implementation of HttpResponse
    infra::BoundedConstString Status() const override;
    void WriteBody(infra::TextOutputStream& stream) const override;
    infra::BoundedConstString ContentType() const override;

private:
    infra::BoundedConstString path;
    application::PostmasterDiscovery& discovery;
    mutable std::string json;
};

HttpPageReverseProxyConfiguration::HttpPageReverseProxyConfiguration(infra::BoundedConstString path, application::PostmasterDiscovery& discovery)
    : path(path)
    , discovery(discovery)
{}

bool HttpPageReverseProxyConfiguration::ServesRequest(const infra::Tokenizer& pathTokens) const
{
    return pathTokens.TokenAndRest(0) == path;
}

void HttpPageReverseProxyConfiguration::RespondToRequest(services::HttpRequestParser& parser, services::HttpServerConnection& connection)
{
    if (parser.Verb() == services::HttpVerb::get)
        connection.SendResponse(*this);
    else
        connection.SendResponse(services::HttpResponseMethodNotAllowed::Instance());
}

infra::BoundedConstString HttpPageReverseProxyConfiguration::Status() const
{
    return services::http_responses::ok;
}

void HttpPageReverseProxyConfiguration::WriteBody(infra::TextOutputStream& stream) const
{
    struct Group
    {
        std::string groupName;
        infra::BoundedConstString attributes;
        std::vector<std::string> urls;
    };

    std::vector<Group> groups;

    int index = 0;
    discovery.EnumerateDiscoveredPostmasters([&groups, &index](const application::PostmasterInfo& postmaster, infra::Duration)
        {
            services::GlobalTracer().Trace() << "Discovered postmaster: " << postmaster.hostname << " with attributes " << postmaster.attributes;

            for (auto& group : groups)
                if (group.attributes == postmaster.attributes)
                {
                    infra::StdStringOutputStream::WithStorage url;
                    url << "http://" << postmaster.ipAddress << "/";
                    group.urls.emplace_back(url.Storage());
                    return;
                }

            infra::StdStringOutputStream::WithStorage serviceName;
            serviceName << "group" << index;
            infra::StdStringOutputStream::WithStorage url;
            url << "http://" << postmaster.ipAddress << "/";
            groups.emplace_back(Group{ serviceName.Storage(), postmaster.attributes, { "http://host.docker.internal:90", url.Storage() } });
            ++index;
        });

    infra::StdStringOutputStream::WithStorage routersFormatterStream;
    {
        infra::JsonObjectFormatter routersFormatter{ routersFormatterStream };
        for (const auto& group : groups)
        {
            auto groupFormatterStream{ routersFormatter.AddObject(group.groupName.c_str()) };
            infra::JsonObjectFormatter groupFormatter{ groupFormatterStream };
            {
                auto entryPoints(groupFormatter.SubArray("entrypoints"));
                entryPoints.Add("http");
            }
            groupFormatter.Add("service", group.groupName);
            infra::StdStringOutputStream::WithStorage rule;
            rule << "PathPrefix(`/" << group.attributes << "`)";
            groupFormatter.Add("rule", rule.Storage());
            {
                auto middlewaresFormatter{ groupFormatter.SubArray("middlewares") };
                middlewaresFormatter.Add(group.groupName);
            }
        }
    }

    infra::StdStringOutputStream::WithStorage middlewaresFormatterStream;
    {
        infra::JsonObjectFormatter middlewaresFormatter(middlewaresFormatterStream);
        for (const auto& group : groups)
        {
            auto redirectionFormatterStream{ middlewaresFormatter.AddObject(group.groupName.c_str()) };
            infra::JsonObjectFormatter redirectionFormatter{ redirectionFormatterStream };
            auto groupFormatterStream{ redirectionFormatter.AddObject("stripPrefix") };
            infra::JsonObjectFormatter groupFormatter{ groupFormatterStream };
            infra::StdStringOutputStream::WithStorage prefix;
            prefix << "/" + group.attributes;
            groupFormatter.Add("prefixes", prefix.Storage());
        }
    }

    infra::StdStringOutputStream::WithStorage servicesFormatterStream;
    {
        infra::JsonObjectFormatter servicesFormatter(servicesFormatterStream);

        for (const auto& group : groups)
        {
            auto pageServerFormatterStream{ servicesFormatter.AddObject(group.groupName.c_str()) };
            infra::JsonObjectFormatter pageServerFormatter{ pageServerFormatterStream };
            auto loadBalancerFormatterStream{ pageServerFormatter.AddObject("loadBalancer") };
            infra::JsonObjectFormatter loadBalancerFormatter{ loadBalancerFormatterStream };
            infra::JsonArrayFormatter serversFormatter{ loadBalancerFormatter.SubArray("servers") };
            for (const auto& url : group.urls)
            {
                infra::JsonObjectFormatter serverFormatter{ serversFormatter.SubObject() };
                serverFormatter.Add("url", url);
            }
        }
    }

    infra::StdStringOutputStream::WithStorage resultFormatterStream;
    {
        infra::JsonObjectFormatter topFormatter(resultFormatterStream);
        auto httpFormatterStream{ topFormatter.AddObject("http") };
        infra::JsonObjectFormatter httpFormatter{ httpFormatterStream };
        httpFormatter.AddSubObject("routers", routersFormatterStream.Storage());
        httpFormatter.AddSubObject("middlewares", middlewaresFormatterStream.Storage());
        httpFormatter.AddSubObject("services", servicesFormatterStream.Storage());
    }

    services::GlobalTracer().Trace() << "Output: " << resultFormatterStream.Storage();

    stream << resultFormatterStream.Storage();
}

infra::BoundedConstString HttpPageReverseProxyConfiguration::ContentType() const
{
    return "text/json";
}

int main(int argc, const char* argv[], const char* env[])
{
    static hal::TimerServiceGeneric timerService;
    static main_::NetworkAdapter network;
    static services::DefaultHttpServer::WithBuffer<2048> httpServer(network.ConnectionFactory(), 90);
    static services::HttpPageWithContent page("page", "<h1>Welcome</h1>", "text/html");

    static main_::MdnsDiscovery discovery{ network.DatagramFactory(), network.Multicast() };

    static services::DefaultHttpServer::WithBuffer<2048> traefikConfigurationServer(network.ConnectionFactory(), 9000);
    static HttpPageReverseProxyConfiguration configuration{ "api", discovery.discovery };

    httpServer.AddPage(page);
    traefikConfigurationServer.AddPage(configuration);

    network.Run();

    return 0;
}

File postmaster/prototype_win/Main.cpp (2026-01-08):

#include "generated/Version.h"
#include "hal/generic/SynchronousRandomDataGeneratorGeneric.hpp"
#include "hal/generic/TimerServiceGeneric.hpp"
#include "hal/windows/UartWindows.hpp"
#include "postmaster/application/MdnsDiscovery.hpp"
#include "postmaster/instantiations/EchoServer.hpp"
#include "postmaster/instantiations/HttpServer.hpp"
#include "postmaster/instantiations/Mdns.hpp"
#include "services/network_instantiations/NetworkAdapter.hpp"
#include "services/st_util/FlashOnStBootloaderCommunicator.hpp"
#include "services/st_util/StBootloaderCommunicatorUart.hpp"
#include "services/tracer/TracerOnIoOutputInfrastructure.hpp"

namespace main_
{
    struct Programmer
    {
        Programmer(application::HttpPageFirmware& page)
            : page(page)
        {
            ReInitialize("Constructing");
        }

        ~Programmer()
        {
            page.ResetReceptor("Destructing");
        }

        void ReInitialize(infra::BoundedConstString reason)
        {
            page.ResetReceptor(reason);
            state.emplace([this]()
                {
                    page.SetReceptor(state->firmwareReceptorToFlash);
                },
                [this](infra::BoundedConstString reason)
                {
                    ReInitialize(reason);
                });
        }

        struct State
        {
            State(const infra::Function<void()>& onInitialized, const infra::Function<void(infra::BoundedConstString reason)>& onError)
                : communicator(serial, onInitialized, onError)
            {}

            hal::UartWindows serial{ "COM11", []()
                {
                    hal::UartWindows::Config config;
                    config.baudRate = CBR_57600;
                    config.parity = hal::UartWindows::Config::Parity::even;
                    return config;
                }() };

            services::StBootloaderCommunicatorUart communicator;
            std::array<uint32_t, 12> sectors{ 0x8000, 0x8000, 0x8000, 0x8000, 0x20000, 0x40000, 0x40000, 0x40000, 0x40000, 0x40000, 0x40000, 0x40000 };
            services::FlashHeterogeneousOnStBootloaderCommunicator communicatorFlash{ sectors, communicator };
            application::FirmwareReceptorToFlash firmwareReceptorToFlash{ communicatorFlash };
        };

        application::HttpPageFirmware& page;
        std::optional<State> state;
    };
}

class ConfigurationStoreInterfaceStub
    : public services::ConfigurationStoreInterface
{
public:
    virtual uint32_t Write() override
    {
        return 0;
    }

    virtual void Unlocked() override
    {}
};

class ResetStub
    : public hal::Reset
{
public:
    void ResetModule(const char* resetReason) override
    {
        std::exit(EXIT_SUCCESS);
    }
};

// clang-format off

class FlashStub
    : public hal::Flash
{
public:
    uint32_t NumberOfSectors() const { return 0; }
    uint32_t SizeOfSector(uint32_t sectorIndex) const { return 0; }
    uint32_t SectorOfAddress(uint32_t address) const { return 0; }
    uint32_t AddressOfSector(uint32_t sectorIndex) const { return 0; }
    void WriteBuffer(infra::ConstByteRange buffer, uint32_t address, infra::Function<void()> onDone) { onDone(); }
    void ReadBuffer(infra::ByteRange buffer, uint32_t address, infra::Function<void()> onDone) { onDone(); }
    void EraseSectors(uint32_t beginIndex, uint32_t endIndex, infra::Function<void()> onDone) { onDone(); }
};

class GpioPinStub
    : public hal::GpioPin
{
public:
    bool Get() const { return false; }
    void Set(bool value) {}
    bool GetOutputLatch() const { return false; }
    void SetAsInput() {}
    bool IsInput() const { return false; }
    void Config(hal::PinConfigType config) {}
    void Config(hal::PinConfigType config, bool startOutputState) {}
    void ResetConfig() {}
    void EnableInterrupt(const infra::Function<void()>& action, hal::InterruptTrigger trigger, hal::InterruptType type = hal::InterruptType::dispatched) {}
    void DisableInterrupt() {}
};

// clang-format on

int main()
{
    static hal::TimerServiceGeneric timerService;
    static hal::SynchronousRandomDataGeneratorGeneric randomDataGenerator;
    static main_::NetworkAdapter networkAdapter;
    static main_::TracerOnIoOutputInfrastructure tracer;

    static ConfigurationStoreInterfaceStub configurationStore;
    static infra::BoundedString::WithStorage<32> hostname{ "postmaster-abc" };
    static infra::BoundedString::WithStorage<64> attributes{ "amp-example" };
    static infra::BoundedString::WithStorage<64> password{ "" };
    static services::ConfigurationStoreAccess<infra::BoundedString> hostnameAccess{ configurationStore, hostname };
    static services::ConfigurationStoreAccess<infra::BoundedString> attributesAccess{ configurationStore, attributes };
    static services::ConfigurationStoreAccess<infra::BoundedString> passwordAccess{ configurationStore, password };

    infra::Creator<hal::SerialCommunication, hal::UartWindows, void(const main_::UartConfig& config)> serialCreator([](std::optional<hal::UartWindows>& value, const main_::UartConfig& config)
        {
            value.emplace("COM13");
        });

    static main_::Mdns mdns{ "richard", networkAdapter.DatagramFactory(), networkAdapter.Multicast(), services::IPv4Address{ 1, 2, 5, 6 }, Postmaster::generated::VERSION, Postmaster::generated::VERSION_FULL, "attributes" };
    static main_::MdnsDiscovery mdnsDiscovery{ networkAdapter.DatagramFactory(), networkAdapter.Multicast() };

    static ResetStub reset;
    static FlashStub flash;
    static GpioPinStub resetTarget;
    static GpioPinStub boot0;
    static application::Authentication authentication{ passwordAccess, randomDataGenerator };
    static main_::HttpServer httpServer{ networkAdapter.ConnectionFactory(), hostnameAccess, attributesAccess, passwordAccess, authentication, mdnsDiscovery.discovery, serialCreator, serialCreator, flash, reset, [](bool open, services::IPAddress address) {}, [](bool receiving) {}, [](bool receiving) {}, resetTarget, boot0 };
    static main_::EchoServer echoServer{ networkAdapter.ConnectionFactory(), serialCreator, 1235 };
    static main_::SingleConnectionLink link(httpServer.server, echoServer.listener);

    networkAdapter.Run();
}

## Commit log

2024-12-04 Initial import of Postmaster
    [Postmaster.brd, Postmaster.sch, Review sheet Postmaster PCB.xlsm]
2025-02-20 feat: add kicad design for Postmaster (#51)
    * feat: redo the schematics and board in KiCad
    * Update schematics
    * Update schematics
    * Update schematics
    * Update schematics
    * Update schematics, add production files
    [Components.csv, Postmaster.kicad_sch, ethernet.kicad_sch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]
2025-04-04 chore: update/add Postmaster PCB
    [Postmaster.kicad_pcb]
2025-04-04 Add production files
    [Components.csv, positions.csv]
2025-04-05 chore: fix the silk layer
    [Postmaster.kicad_pcb]
2025-05-08 feat: publish flex docker image (#5)
    * feat: publish flex docker image
    * flex-build-push.yml: rename docker image
    * Add healthcheck to Dockerfile.flex
    * Optionally read options from environment
    * postmaster/flex/Main: Fix reading from environment
    * postmaster/flex/Main: Fix reading from environment
    * postmaster/flex/Main: Allow selection of destination port
    * .github/workflows/flex-build-push: remove merge group and multi platform support
    [Main.cpp]
2025-05-10 fix: attach from correct SharedPtr
2025-05-22 fix: align flash writes to 16 bytes (#80)
    * fix: align flash writes to 16 bytes
    * Wait for flash initialization done
    * FlexHttpClient: Move attaching of websocket
    * FirmwareReceptorResetTarget: Use timers instead of HAL_Delay
    * Set starting
    * Update container
    * Flush aligned buffer on end of reception
    * Reset when reception is completely stopped
    * Update amp-hal-st
2025-10-24 chore: update submodules (#121)
    * chore: update submodules
    * Fix Main
    [Main.cpp]
2025-10-27 Revert "chore: update submodules (#121)" (#123)
    This reverts commit 6eb1c4b0b4ba273aa7b27818f57eee4a6591189f.
    [Main.cpp]
2025-11-07 chore: update submodules (#128)
    * Reapply "chore: update submodules (#121)" (#123)
    This reverts commit 3064c407f69a62eb0b16d691f774db688fc56660.
    * Zero-terminate hostname
    * Invoke lambda
    [Main.cpp]
2026-01-05 fix: install postmaster binaries (#146)
    * fix: install postmaster binaries
    * Add map and hex files
    * Create and release upgrade pack
    * Fix character
    * Move Build Upgrade Pack to continuous-integration.yml
    * Fix artifact name
    * Remove duplicate mkdir install
    * Avoid moving to an existing directory
    [Main.cpp]
2026-01-06 fix: release version in upg file names (#160)
    * fix: release version in upg file names
    * Update version
    [Main.cpp]
2026-01-08 fix: firmware upgrade (#167)
    * fix: firmware upgrade
    * Give read permissions
    * Quotes
    * More permissions
    * Remove permissions
    [Main.cpp]
